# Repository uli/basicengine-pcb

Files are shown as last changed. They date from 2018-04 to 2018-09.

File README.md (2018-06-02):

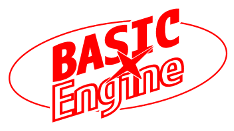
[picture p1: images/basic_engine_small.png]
BASIC Engine logo
#  BASIC Engine PCB

The BASIC Engine is a very low-cost single-board home computer with advanced 
2D color graphics and sound capabilities, roughly comparable to late-1980s
or early-1990s computers and video game consoles.  It can be built at home
without special skills or tools and using readily available components for
under 10 Euros in parts, or mass-produced for even less.

This repository contains KiCAD schematics and the PCB layout. Gerber files
for ordering PCBs can be found in the [release section](https://github.com/uli/basicengine-pcb/releases).

Software can be found in the [BASIC Engine firmware](https://github.com/uli/basicengine-firmware)
repository.

## Hardware features

- ESP12-E/F module with ESP8266 SoC and 4 MB flash memory
- VS23S010 video controller with 128k RAM and composite video output in PAL or NTSC
- 5-bit PCM sound from I2S controller
- MicroSD card slot
- PS/2 and PS/2-compatible USB keyboard interface
- PlayStation controller port
- PCF8575 I/O extender with 16 GPIO pins
- I2C and SPI busses on I/O expansion connector
- power supplied via Micro-USB socket or pin header
- RCA connectors for video and audio

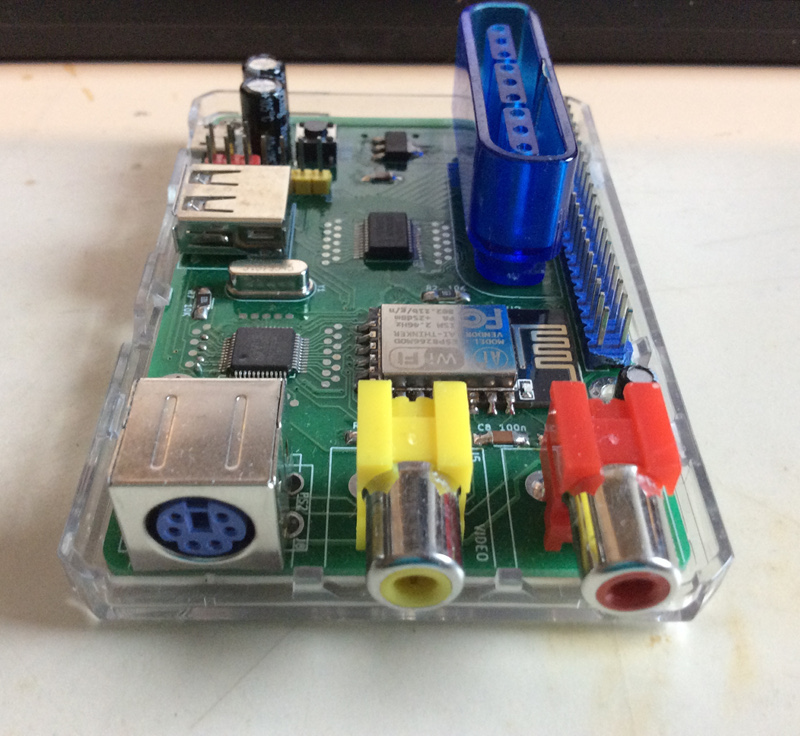
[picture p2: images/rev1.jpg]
Revision 1 board


## Components

The BASIC Engine does not use any obsolete components that may be difficult
to obtain.  Nevertheless, you will have to put in at least three orders to
get all required parts.

I would recommend to get the circuit board from JLCPCB or Smart Prototyping,
the VS23S010D-L chip from TME, and all other parts from AliExpress.  AE
usually has the lowest price, and this project is all about the cheap.

You will usually have to order more components than you actually intend to
use, because
- they are only offered in larger quantities,
- you may want to save on shipping in case you decide to build more BASIC Engines,
- you are likely to break or lose a few parts while building the device, or
- all of the above.

**Note:** Unless noted otherwise, all links lead to suppliers and components
I have bought myself in the past and that have received the "Good Enough for
BASIC Engine" seal of approval.  Nevertheless you **order at your own
risk**, and I cannot be held responsible for the quality of the services or
products provided to you.  I am not affiliated with any of the linked
suppliers.

### Required components

|Qty	|Name				|Package|Where to get it					|Links|
|---|---|---|---|-----|
|1	|Circuit Board			|	|Any board house					|[JLCPCB](https://jlcpcb.com/quote), [Smart Prototyping](https://www.smart-prototyping.com/PCB-Prototyping.html).
|1	|VS23S010D-L video controller	|	|TME (small quantities), VLSI (for large orders)	|[TME](https://www.tme.eu/en/details/vs23s010d-l/parallel-sram-memories-integ-circ/vlsi/), [VLSI](https://webstore.vlsi.fi/epages/vlsi.sf/en_GB/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)
|1	|ESP-12F or ESP-12E microcontroller module|	|AliExpress, eBay, Amazon, various smaller retailers	|AliExpress: [1](https://www.aliexpress.com/item/New-version-ESP-12E-replace-ESP-12-ESP8266-remote-serial-Port-WIFI-wireless-module/32339917567.html), [2](https://www.aliexpress.com/item/1PCS-ESP-12F-ESP-12E-upgrade-ESP8266-Remote-Serial-Port-WIFI-Wireless-Module-ESP8266-4M-Flash/32521015580.html), [3](https://www.aliexpress.com/item/1PCS-ESP-12F-ESP-12E-upgrade-ESP8266-Remote-Serial-Port-WIFI-Wireless-Module-ESP8266-4M-Flash/32521015580.html)
|8	|Resistor 10K			|1206	|Generic part						|AliExpress: [1](https://www.aliexpress.com/item/500pcs-1206-SMD-Resistor-1-10K-ohm-chip-resistor-0-25W-1-4W-103/32806664929.html), [2](https://www.aliexpress.com/item/1206-10K-ohm-5-1-4W-Resistor-3216-103-Chip-resistor-500Pcs-Lot/32601535320.html)
|1	|Resistor 1M			|1206	|Generic part						|AliExpress: [1](https://www.aliexpress.com/item/500pcs-1206-SMD-Resistor-1-1M-ohm-chip-resistor-0-25W-1-4W-106/32806720513.html)
|1	|Resistor 75 Ohms		|1206	|Generic part						|AliExpress: [1](https://www.aliexpress.com/item/100pcs-lot-1206-5-75-ohm-75R-750-1-4W-0-25W-SMD-Resistor-3-2/32681304598.html), [2 (untested supplier)](https://www.aliexpress.com/item/200pcs-lot-SMD-Chip-Resistor-1206-68R-75R-82R-91R-100R-5-Resistance-68-75-82/32830700367.html)
|2	|Resistor 1K			|1206	|Generic part						|AliExpress: [1](https://www.aliexpress.com/item/500pcs-1206-SMD-Resistor-1-1K-ohm-chip-resistor-0-25W-1-4W-102/32806736163.html)
|8	|Capacitor 100nF		|1206	|Generic part						|AliExpress: [1](https://www.aliexpress.com/item/100pcs-100NF-X7R-Error-10-50V-0-1UF-104-1206-smd-capacitor/32810080501.html), [2](https://www.aliexpress.com/item/100PCS-SMD-chip-Ceramic-capacitors-1206-104-100NF-0-1UF-1206-Y5V/1478483210.html), [3](https://www.aliexpress.com/item/100PCS-1206-104-100NF-0-1UF-1206-SMD-capacitance/32836586837.html), [4](https://www.aliexpress.com/item/Free-Shipping-100PCS-1206-104-100NF-0-1UF-1206-SMD-capacitance/1096160798.html)
|2	|Capacitor 56pF			|1206	|Generic part						|AliExpress: [1](https://www.aliexpress.com/item/100pcs-1206-smd-capacitor-25pF-27pF-30pF-33pF-36pF-39pF-47pF-51pF-56pF-68pF/32832398866.html)
|1	|Electrolytic capacitor 10uF (**Revision 1 board only!**)	|THT	|Generic part		|AliExpress: [1](https://www.aliexpress.com/item/Free-shiiping-50pcs-Aluminum-electrolytic-capacitor-10uF-50V-5-7-Electrolytic-capacitor/32326606304.html), [2](https://www.aliexpress.com/item/50-pcs-Electrolytic-Capacitors-50V-10UF-4X7MM-Aluminum-Electrolytic-Capacitor/1808204181.html)
|2	|Electrolytic Capacitor 220uF (**Revision 1 board only!**)	|THT	|Generic part		|AliExpress: [1](https://www.aliexpress.com/item/1LOT-50PCS-Aluminum-Capacitors-220uF-227-20-6-11mm-25V-220000nF-220000000pF-Diameter6mm/32707926097.html)
|1	|Capacitor 10uF (**Revision 2 board only!**)|1206	|Generic part				|AliExpress: [1](https://www.aliexpress.com/item/Free-Shopping-100PCS-smd-ceramic-capacitor-1206-3216-10uf-106-25V-10/870636274.html), [2](https://www.aliexpress.com/store/product/100PCS-LOT-10uf-Error-10-50V-106-10UF-1206-SMD-Thick-Film-Chip-Multilayer-Ceramic-Capacitor/1815642_32818359105.html)
|2	|Capacitor 22uF (**Revision 2 board only!**)|1206	|Generic part				|AliExpress: [1](https://www.aliexpress.com/item/1206-22UF-226M-Y5V-10V-SMD-Chip-Multilayer-Ceramic-Capacitor-Capacitor/32506900002.html), [2](https://www.aliexpress.com/item/100PCS-LOT-22uf-Error-10-50V-226-22UF-1206-SMD-Thick-Film-Chip-Multilayer-Ceramic-Capacitor/32818355106.html)
|2	|RCA connectors			|THT	|Generic, but often overpriced part			|AliExpress: [1 (untested supplier)](https://www.aliexpress.com/item/ROHS-high-quality-one-pin-rca-jack-connector-RCA-103P/32305697673.html); no longer available: [red](https://www.aliexpress.com/item/10-Pcs-Pcb-Mount-3-Pin-Av-Concentric-Outlet-1-Rca-Female-Socket-Board-Connector/32778665156.html), [yellow](https://www.aliexpress.com/item/20-Pcs-3P-Pcb-Mounting-Yellow-1-Rca-Female-Outlet-Jack-Audio-Video-Av-Connector/32773151735.html)
|1	|Micro-USB connector		|SMT	|Generic, but often overpriced part			|AliExpress: [1](https://www.aliexpress.com/item/10Pcs-Micro-USB-5P-5-pin-Micro-USB-Jack-5Pins-No-Curling-Micro-USB-Connector-Tail/32697562974.html), [2](https://www.aliexpress.com/item/10pcs-LOT-Micro-USB-5P-5-pin-Micro-USB-Jack-5Pins-Micro-USB-Connector-Tail-Charging/32482316889.html), [3](https://www.aliexpress.com/item/10pcs-G21-Micro-USB-5pin-DIP-Female-Connector-For-Mobile-Phone-Mini-USB-Charging-Socket-Curly/32739335401.html), [4](https://www.aliexpress.com/item/50pcs-Lot-Micro-USB-5pin-B-type-Female-Connector-For-Mobile-Phone-Micro-USB-Jack-Connector/32740232877.html)
|1	|Regulator AMS1117 3.3V		|SOT-223|Generic, sometimes overpriced part			|AliExpress: [1](https://www.aliexpress.com/item/10pcs-AMS1117-3-3-AMS1117-LM1117-1117-3-3V-1A-Voltage-Regulator/32348815272.html); eBay DE: [1](https://www.ebay.de/itm/50-Stueck-AMS1117-3-3-Niedrig-Aussetzer-Spannungsregler-3-3V-1A-SOT-223-GY-/262752156305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)
|1	|74HC04 hex inverter		|SOIC-14|Generic part						|AliExpress: [1](https://www.aliexpress.com/item/20PCS-74HC04D-SOP14-74HC04-SOP-SN74HC04DR-SMD-new-and-original-IC-free-shipping/32545540311.html), [2](https://www.aliexpress.com/item/20PCS-74HC04-SOP/32833871593.html)
|1	|Crystal 3.579545 MHz (NTSC) or 4.433619 MHz (PAL)|HC49-S	|Generic part				|AliExpress: [NTSC](https://www.aliexpress.com/item/10pcs-lot-Crystal-Oscillator-3-579545MHz-3-579545-MHz3-579545M-Hz-3-579545M-Mini-Passive-Resonator/32674141136.html), [PAL (untested supplier)](https://www.aliexpress.com/item/4-433MHZ-4-433M-HC-49S-Quartz-crystal-4-433Mhz-4-433m-DIP-Quartz-crystal-resonators/897579150.html)
|1	|PS/2 keyboard connector (female)|THT	|AliExpress, some distributors				|AliExpress: [green](https://www.aliexpress.com/item/20PCS-Lot-PS2-Green-Plug-Jack-Socket-Connector-6Pin-for-keyboard-mouse/32502046263.html), [purple](https://www.aliexpress.com/item/20PCS-Lot-PS2-Purple-Plug-Jack-Socket-Connector-6P-6Pin-for-keyboard-mouse/32503500361.html)

### Not strictly required, but strongly recommended components

|Qty	|Name				|Package|Who can supply it					|Links|
|---|---|---|---|-----|
|1	|Pin header 1x7 (programming header)|	|Generic part						|AliExpress: [1](https://www.aliexpress.com/item/1-pcs-color-2-54mm-Black-White-Red-Yellow-Blue-Green-1X40-Single-Row-Pin-Male/32776690848.html) (1x40 headers, cut them to size)
|1	|MicroSD socket			|SMT	|AliExpress, eBay					|AliExpress: [1](https://www.aliexpress.com/item/10pcs-MicroSD-Card-socket-connector-pop-up/1878206296.html), [2](https://www.aliexpress.com/item/Free-Shipping-10PCS-MicroSD-Card-socket-connector-pop-up/1688131297.html); eBay DE: [1](https://www.ebay.de/itm/10Pcs-TransFlash-SD-TF-Micro-Memory-Card-Self-eject-Socket-Adapter-Plug-NEW-/272247684402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)
|1	|Push button 6x6x4.3 mm		|THT	|Generic part						|AliExpress: [1](https://www.aliexpress.com/item/10PCS-TC-1212T-6x6x4-3-mm-Tact-Tactile-Push-Button-Momentary-SMD-PCB-Switch/32633194631.html), [2](https://www.aliexpress.com/item/20PCS-6X6X4-3-DIP-vertical-Tactile-Tact-Push-Button-Switch-Micro-Switch-Momentary-6-6-4/32628754816.html)
|1	|PCF8575TS I2C I/O extender	|SSOP-24|Generic part; AliExpress recommended for price		|AliExpress: [1](https://www.aliexpress.com/item/5PCS-PCF8575TS-SSOP24-PCF8575-SOP24/32836090166.html)
|1	|Raspberry Pi 3 case		|	|Generic part						|AliExpress: [1](https://www.aliexpress.com/item/case-H1-Black-Raspberry-PI-3-model-B-Case-Cover-Shell-Enclosure-ABS-Plastic-Box-for/32813179636.html), [2](https://www.aliexpress.com/item/box-F3-for-Raspberry-PI-3-model-B-Transparent-Green-Case-Cover-Shell-Enclosure-Box/32824924648.html), [3](https://www.aliexpress.com/item/10pcs-lot-Raspberry-Pi-3-case-Official-ABS-enclosure/32816503175.html), [4](https://www.aliexpress.com/item/New-Arrival-Raspberry-Pi-3-Model-B-Case-Black-Red-ABS-Plastic-Box-Closed-Cover-Shell/32716194619.html), [5](https://www.aliexpress.com/item/Raspberry-Pi-3-Model-B-ABS-Case-Black-White-Tranparent-ABS-Enclosure-Box-Shell-for-Raspberry/32651704900.html)

### Optional components

|Qty	|Name				|Package|Who can supply it					|Links|
|---|---|---|---|-----|
|1	|Pin header 1x3 pins (alternative power supply)|	|AliExpress recommended for price	|see "Pin header 1x7"
|1	|USB A connector (alternative keyboard connector)|THT	|Generic part				|AliExpress: [1](https://www.aliexpress.com/item/10-PCS-USB-Type-A-Female-PCB-Mount-Socket-Plug-Connector-Right-Angle-4-Pin-New/32821630374.html), [2](https://www.aliexpress.com/item/10PCS-USB-type-A-USB-mother-Curved-needle/32265708803.html)
|1	|Pin header 2x20 pins (expansion connector)|	|AliExpress recommended for price		|AliExpress: [1](https://www.aliexpress.com/item/30-pcs-set-2-54mm-Black-White-Red-Yellow-Blue-Green-2X40-Double-Row-Pin-Male/32776804458.html) (2x40 headers, cut them in half)
|1	|PlayStation controller connector (female)|	|AliExpress					|AliExpress: [1](https://www.aliexpress.com/item/10pcs-wholesale-Replacement-9-Pin-Female-Connector-Game-Controller-Socket-Slot-for-PS2-Console-for-playstation/32769355434.html), [2](https://www.aliexpress.com/item/10pcs-Replacement-9-Pin-90-degrees-Female-Connector-Game-Controller-Socket-Slot-for-PS2-Console/32818887920.html)

### Programming tools

Used to flash the firmware into the microcontroller module. You only need one set of these.

|Qty	|Name				|Package|Who can supply it				|Links|
|---|---|---|---|-----|
|1	|USB-to-serial converter	|	|AliExpress, eBay				|AliExpress: [1](https://www.aliexpress.com/item/1pcs-FT232RL-FTDI-USB-3-3V-5-5V-to-TTL-Serial-Adapter-Module-forArduino-Mini-Port/32650148276.html), [2](https://www.aliexpress.com/item/CP2102-USB-2-0-to-TTL-UART-Module-6Pin-Serial-Converter-STC-Replace-FT232-Module/32279672853.html)
|7	|Dupont wires female/female (for wiring the converter to the programming header)|	|AliExpress, eBay	|AliExpress: [1 (untested supplier)](https://www.aliexpress.com/item/40pcs-dupont-cable-jumper-wire-dupont-line-female-to-female-dupont-line-20cm-1P-40P-free/32848338475.html), [2 (untested supplier)](https://www.aliexpress.com/item/40pcs-dupont-cable-jumper-wire-dupont-line-female-to-female-dupont-line-20cm-1P-1P-for/32586620163.html)

## Ordering the PCB

If you have never had a custom circuit board made, you may find the
multitude of options you are presented with on the board house's ordering
page confusing.  The good news is that you do not have to worry about most
of them, because they have been set to reasonable defaults already.  If you
order with JLCPCB or Smart Prototyping using the links above, all you have
to do is upload the ZIP file containing the Gerber files that you can find
in the [release section](https://github.com/uli/basicengine-pcb/releases)
and specify the dimensions of the board (85x56 mm).  All other options can
be left as is.

(Just to be on safe side: At the time of writing these options were: 2
layers, 1.6 mm thickness, HASL with lead, 1oz copper weight, material FR4.)

## Assembling the BASIC Engine

Even though it uses some small-pitch components, the BASIC Engine has been
designed to be easy to assemble.

Click on the thumbnail below to watch a one-hour silent video showing how to
build it using a soldering iron, a heat gun, tweezers,
solder wire and side cutters, without fancy tools, mad soldering skills and
with only a minimal amount of patience:

Assembling the BASIC Engine (http://www.youtube.com/watch?v=DTTEZJDEUIA "BASIC Engine Soldering")

## PCB Errata

Revision 2 of the PCB contains one error:

- R6 value is given as "22R", should be "75R".

Revision 1 of the PCB contains two errors:

- R6 value is given as "22R", should be "75R".
- C3 and C4 values are given as "10p", should be "56p".

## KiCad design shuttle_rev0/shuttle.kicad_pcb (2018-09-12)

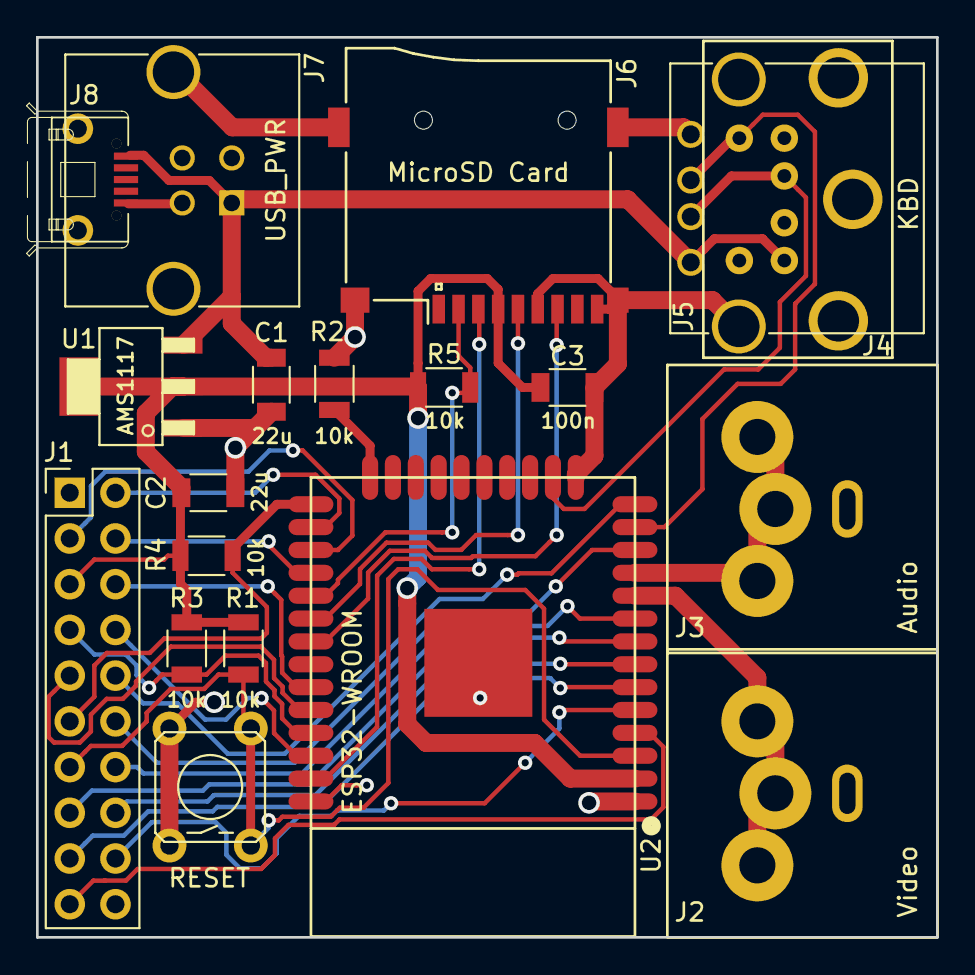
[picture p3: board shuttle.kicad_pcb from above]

Board: 2 copper layers, 50.0 x 50.0 mm, 19 parts (0 on the bottom side), 29 nets.

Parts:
C1, C2: 22u; C_1206
C3: 100n; C_1206
J1: EXP; Pin_Header_Straight_2x10_Pitch2.54mm
J2: Video; rca_uni
J3: Audio; rca_uni
J4: PS2_KBD; MINI-DIN-6-FULL-SHIELD
J5: KBD; USB_A
J6: MicroSD Card; Conn_uSDcard
J7: USB_PWR; USB_B_MUSB_Straight
J8: USB_PWR_U; AB2_USB_MICRO_SMD
R1, R2, R3, R4, R5: 10k; R_1206
SW1: RESET; AB2_PB_MOM_6MM_PTH_BLK
U1: AMS1117; AB2_SOT223
U2: ESP32-WROOM

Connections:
+5V: C1.1, J4.4, J5.1, J7.1, J8.1, U1.3
/3V3: C2.1, C3.1, J1.5, J6.4, R1.2, R3.1, R4.1, R5.1, U1.2, U2.2
/AUDIO: J3.1, U2.11
/DBG_DTR: J1.11, R4.2, U2.25
/DBG_RX: J1.9, U2.34
/DBG_TX: J1.7, R3.2, U2.35
/EN: J1.13, R1.1, SW1.2, U2.3
/GPIO2: R2.1, U2.24
/GPIO4: J1.2, U2.26
/GPIO12: J1.10, U2.14
/GPIO16: J1.3, U2.27
/GPIO17: J1.4, U2.28
/GPIO21: J1.6, U2.33
/GPIO22: J1.8, U2.36
/GPIO27: J1.12, U2.12
/GPIO32: J1.15, U2.8
/GPIO33: J1.14, U2.9
/GPIO34: J1.17, U2.6
/GPIO35: J1.16, U2.7
/MISO: J6.7, U2.31
/MOSI: J6.3, U2.37
/PS2CLK: J4.5, J5.3, U2.13
/PS2DAT: J4.1, J5.2, U2.16
/SCLK: J6.5, U2.30
/SDCS: J6.2, R5.2, U2.29
/SENSOR_VN: J1.18, U2.5
/SENSOR_VP: J1.19, U2.4
/VIDEO: J2.1, U2.10
GND: C1.2, C2.2, C3.2, J1.1, J1.20, J2.2, J3.2, J4.3, J5.4, J5.5, J6.6, J6.9, J7.4, J7.5, J8.5, R2.2, SW1.1, U1.1, U2.1, U2.15, U2.38, U2.39

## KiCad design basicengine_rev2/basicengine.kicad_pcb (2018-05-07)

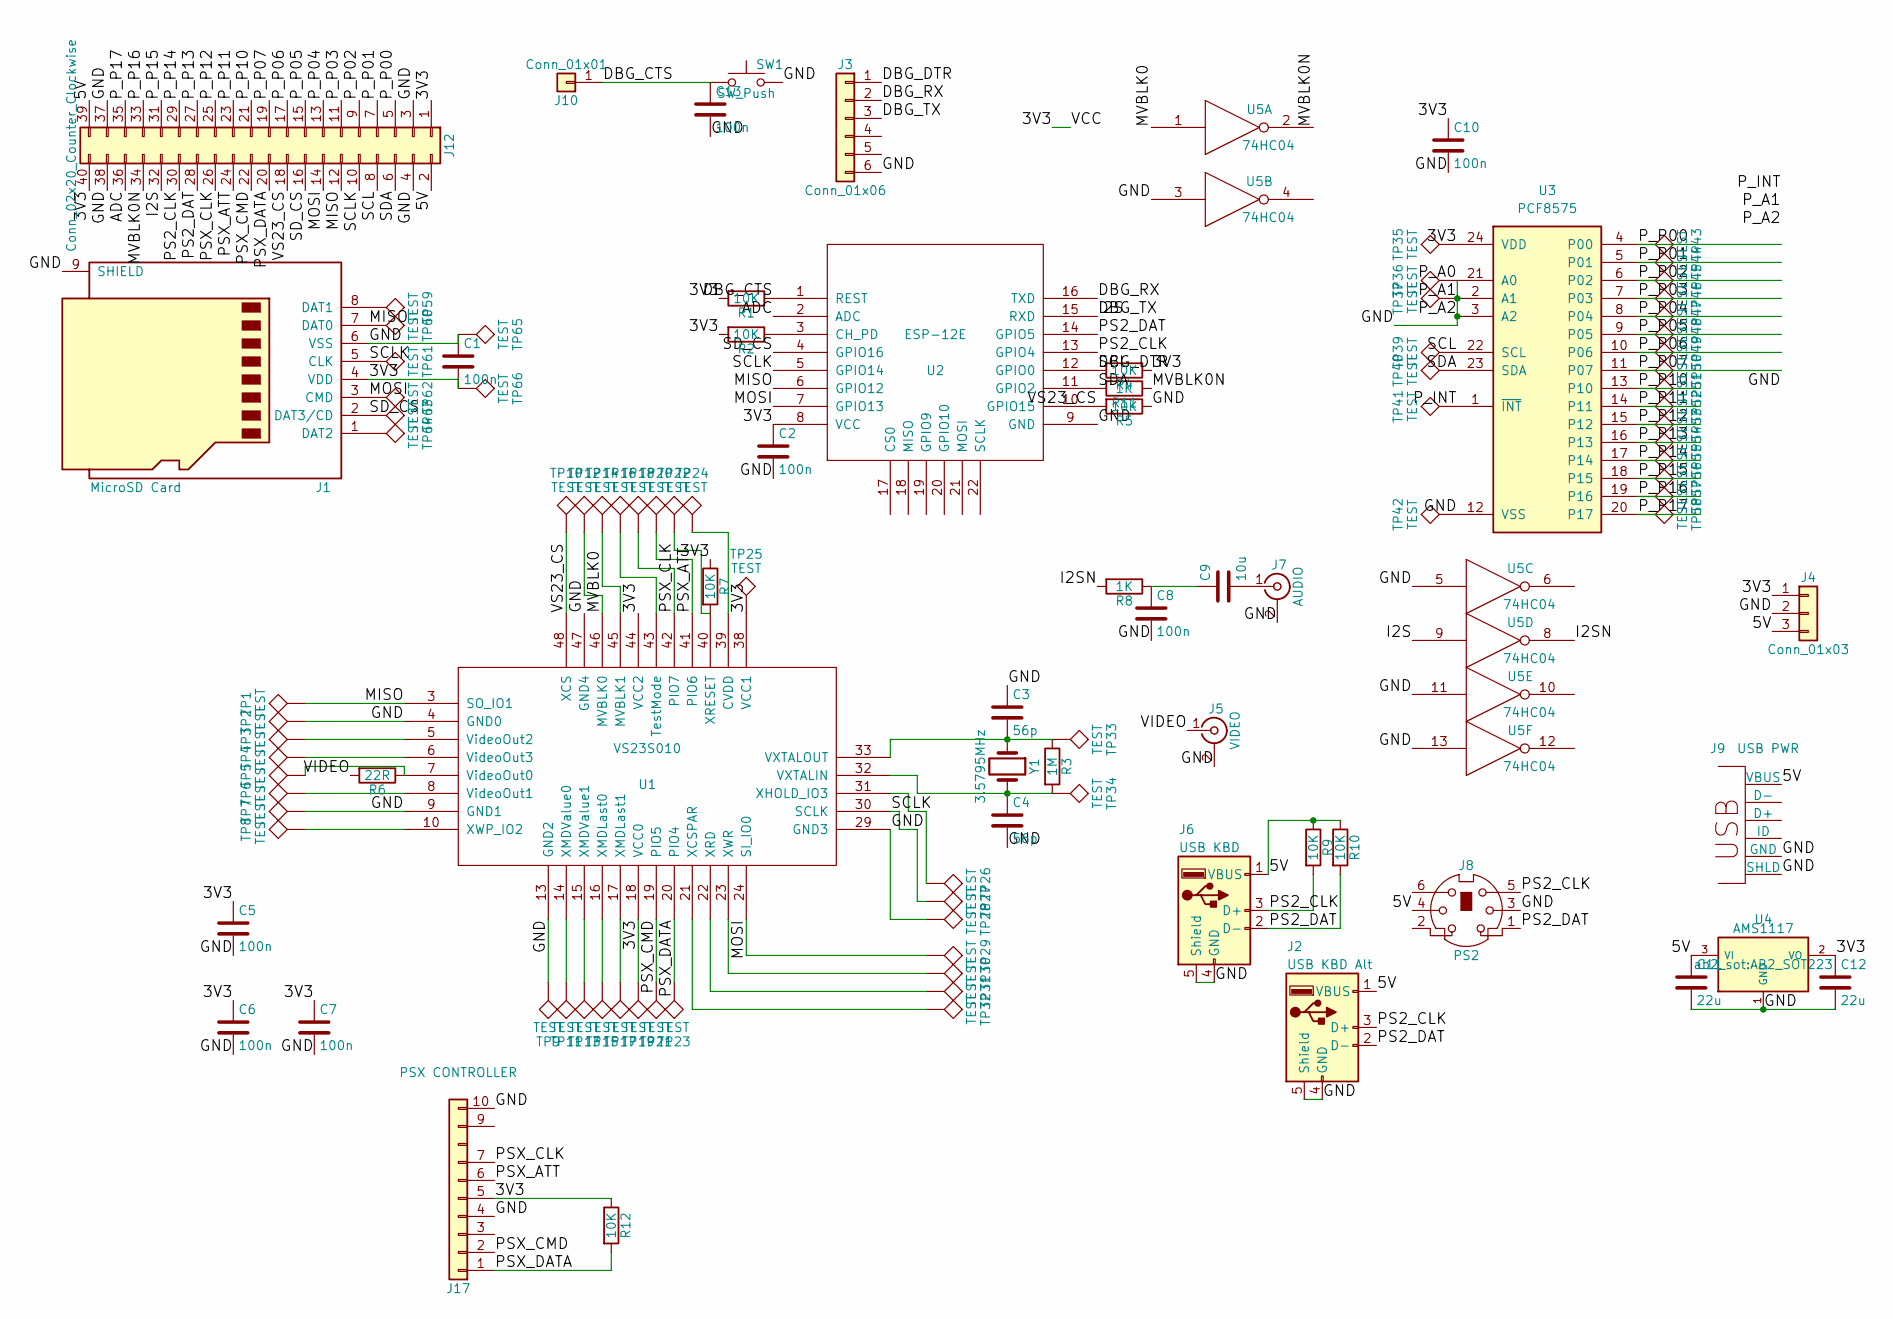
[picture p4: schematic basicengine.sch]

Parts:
C1, C2, C5, C6, C7, C8, C10, C13: 100n; C_1206_HandSoldering
C3, C4: 56p; C_1206_HandSoldering
C9: 10u; C_1206_HandSoldering
C11, C12: 22u; C_1206_HandSoldering
J1: MicroSD Card; Conn_uSDcard
J2: USB KBD Alt; USB_A
J3: Conn_01x06; Pin_Header_Straight_1x06
J4: Conn_01x03; Pin_Header_Straight_1x03
J5: VIDEO; rca
J6: USB KBD; USB_A
J7: AUDIO; rca
J8: PS2; MINI-DIN-6-FULL-SHIELD
J9: USB PWR; AB2_USB_MICRO_SMD
J10: Conn_01x01; Pin_Header_Straight_1x01
J12: Conn_02x20_Counter_Clockwise; Pin_Header_Straight_2x20
J17: PSX CONTROLLER; psx-con-female
R1, R2, R4, R5, R7, R9, R10, R12: 10K; R_1206_HandSoldering
R3: 1M; R_1206_HandSoldering
R6: 22R; R_1206_HandSoldering
R8, R11: 1K; R_1206_HandSoldering
SW1: SW_Push; AB2_PB_MOM_6MM_PTH_BLK
TP1, TP2, TP3, TP4, TP5, TP6, TP7, TP8, TP9, TP10, TP11, TP12, TP13, TP14, TP15, TP16, TP17, TP18, TP19, TP20, TP21, TP22, TP23, TP24, TP25, TP26, TP27, TP28, TP29, TP30, TP31, TP32, TP33, TP34, TP35, TP36, TP37, TP39, TP40, TP41, TP42, TP43, TP44, TP45, TP46, TP47, TP48, TP49, TP50, TP51, TP52, TP53, TP54, TP55, TP56, TP57, TP58, TP59, TP60, TP61, TP62, TP63, TP64, TP65, TP66: TEST; Measurement_Point_Round-SMD-Pad_Small
U1: VS23S010; LQFP-48_7x7mm_Pitch0.5mm
U2: ESP-12E; ESP-12E_SMD
U3: PCF8575; SSOP-24_5.3x8.2mm_Pitch0.65mm; MPN PCF8575TS/1,112
U4: AMS1117; AB2_SOT223
U5: 74HC04; SOIC-14_3.9x8.7mm_Pitch1.27mm
Y1: 3.5795MHz; Crystal_HC49-U_Vertical

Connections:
/5V: C11.1, J2.1 (VBUS), J4.3, J6.1 (VBUS), J8.4, J9.1 (VBUS), J12.2, J12.39, R9.1, R10.1, U4.3 (VI)
/ADC: J12.36, U2.2 (ADC)
/DBG_CTS: C13.1, J10.1, R1.1, SW1.1, U2.1 (REST)
/DBG_DTR: J3.1, J12.8, R4.2, TP39.1, U2.12 (GPIO0), U3.22 (SCL)
/DBG_RX: J3.2, U2.16 (TXD)
/DBG_TX: J3.3, J12.32, U2.15 (RXD), U5.9
/I2SN: R8.2, U5.8
/MISO: J1.7 (DAT0), J12.12, TP1.1, TP60.1, U1.3 (SO_IO1), U2.6 (GPIO12)
/MOSI: J1.3 (CMD), J12.14, TP29.1, TP62.1, U1.24 (SI_IO0), U2.7 (GPIO13)
/MVBLK0: TP12.1, U1.46 (MVBLK0), U5.1
/MVBLK0N: J12.34, R11.1, U5.2
/PS2_CLK: J2.3 (D+), J6.3 (D+), J8.5, J12.30, R9.2, U2.13 (GPIO4)
/PS2_DAT: J2.2 (D-), J6.2 (D-), J8.1, J12.28, R10.2, U2.14 (GPIO5)
/PSX_ATT: J12.24, J17.6, TP20.1, U1.41 (PIO6)
/PSX_CLK: J12.26, J17.7, TP18.1, U1.42 (PIO7)
/PSX_CMD: J12.22, J17.2, TP21.1, U1.19 (PIO5)
/PSX_DATA: J12.20, J17.1, R12.2, TP23.1, U1.20 (PIO4)
/P_INT: TP41.1, U3.1 (~INT)
/P_P00: J12.5, TP43.1, U3.4 (P00)
/P_P01: J12.7, TP44.1, U3.5 (P01)
/P_P02: J12.9, TP45.1, U3.6 (P02)
/P_P03: J12.11, TP46.1, U3.7 (P03)
/P_P04: J12.13, TP47.1, U3.8 (P04)
/P_P05: J12.15, TP48.1, U3.9 (P05)
/P_P06: J12.17, TP49.1, U3.10 (P06)
/P_P07: J12.19, TP50.1, U3.11 (P07)
/P_P10: J12.21, TP51.1, U3.13 (P10)
/P_P11: J12.23, TP52.1, U3.14 (P11)
/P_P12: J12.25, TP53.1, U3.15 (P12)
/P_P13: J12.27, TP54.1, U3.16 (P13)
/P_P14: J12.29, TP55.1, U3.17 (P14)
/P_P15: J12.31, TP56.1, U3.18 (P15)
/P_P16: J12.33, TP57.1, U3.19 (P16)
/P_P17: J12.35, TP58.1, U3.20 (P17)
/SCLK: J1.5 (CLK), J12.10, TP27.1, TP61.1, U1.30 (SCLK), U2.5 (GPIO14)
/SDA: J12.6, R11.2, TP40.1, U2.11 (GPIO2), U3.23 (SDA)
/SD_CS: J1.2 (DAT3/CD), J12.16, TP63.1, U2.4 (GPIO16)
/VIDEO: J5.1 (In), R6.2
/VS23_CS: J12.18, R5.2, TP10.1, U1.48 (XCS), U2.10 (GPIO15)
GND: C1.1, C2.2, C3.1, C4.2, C5.2, C6.2, C7.2, C8.2, C10.2, C11.2, C12.2, C13.2, J1.6 (VSS), J1.9 (SHIELD), J2.4 (GND), J2.5 (Shield), J3.6, J4.2, J5.2 (Ext), J6.4 (GND), J6.5 (Shield), J7.2 (Ext), J8.3, J9.5 (GND), J9.SH (SHLD), J12.3, J12.4, J12.37, J12.38, J17.4, J17.10, R5.1, SW1.2, TP2.1, TP7.1, TP9.1, TP28.1, TP36.1, TP37.1, TP42.1, TP65.1, U1.4 (GND0), U1.9 (GND1), U1.13 (GND2), U1.29 (GND3), U1.47 (GND4), U2.9 (GND), U3.2 (A1), U3.3 (A2), U3.12 (VSS), U3.21 (A0), U4.1 (GND), U5.3, U5.5, U5.7 (GND), U5.11, U5.13
unnamed: C3.2, R3.1, TP33.1, U1.33 (VXTALOUT), Y1.1
unnamed: C4.1, R3.2, TP34.1, U1.32 (VXTALIN), Y1.2
unnamed: C8.1, C9.1, R8.1
unnamed: C9.2, J7.1 (In)
unnamed: J1.1 (DAT2), TP64.1
unnamed: J1.8 (DAT1), TP59.1
unnamed: R2.1, U2.3 (CH_PD)
unnamed: R6.1, TP5.1, U1.7 (VideoOut0)
unnamed: R7.2, TP22.1, U1.40 (XRESET)
unnamed: TP3.1, U1.5 (VideoOut2)
unnamed: TP4.1, U1.6 (VideoOut3)
unnamed: TP6.1, U1.8 (VideoOut1)
unnamed: TP8.1, U1.10 (XWP_IO2)
unnamed: TP11.1, U1.14 (XMDValue0)
unnamed: TP13.1, U1.15 (XMDValue1)
unnamed: TP14.1, U1.45 (MVBLK1)
unnamed: TP15.1, U1.16 (XMDLast0)
unnamed: TP16.1, U1.43 (TestMode)
unnamed: TP17.1, U1.17 (XMDLast1)
unnamed: TP24.1, U1.39 (CVDD)
unnamed: TP26.1, U1.31 (XHOLD_IO3)
unnamed: TP30.1, U1.23 (XWR)
unnamed: TP31.1, U1.22 (XRD)
unnamed: TP32.1, U1.21 (XCSPAR)
VCC: C1.2, C2.1, C5.1, C6.1, C7.1, C10.1, C12.1, J1.4 (VDD), J4.1, J12.1, J12.40, J17.5, R1.2, R2.2, R4.1, R7.1, R12.1, TP19.1, TP25.1, TP35.1, TP66.1, U1.18 (VCC0), U1.38 (VCC1), U1.44 (VCC2), U2.8 (VCC), U3.24 (VDD), U4.2 (VO), U5.14 (VCC)

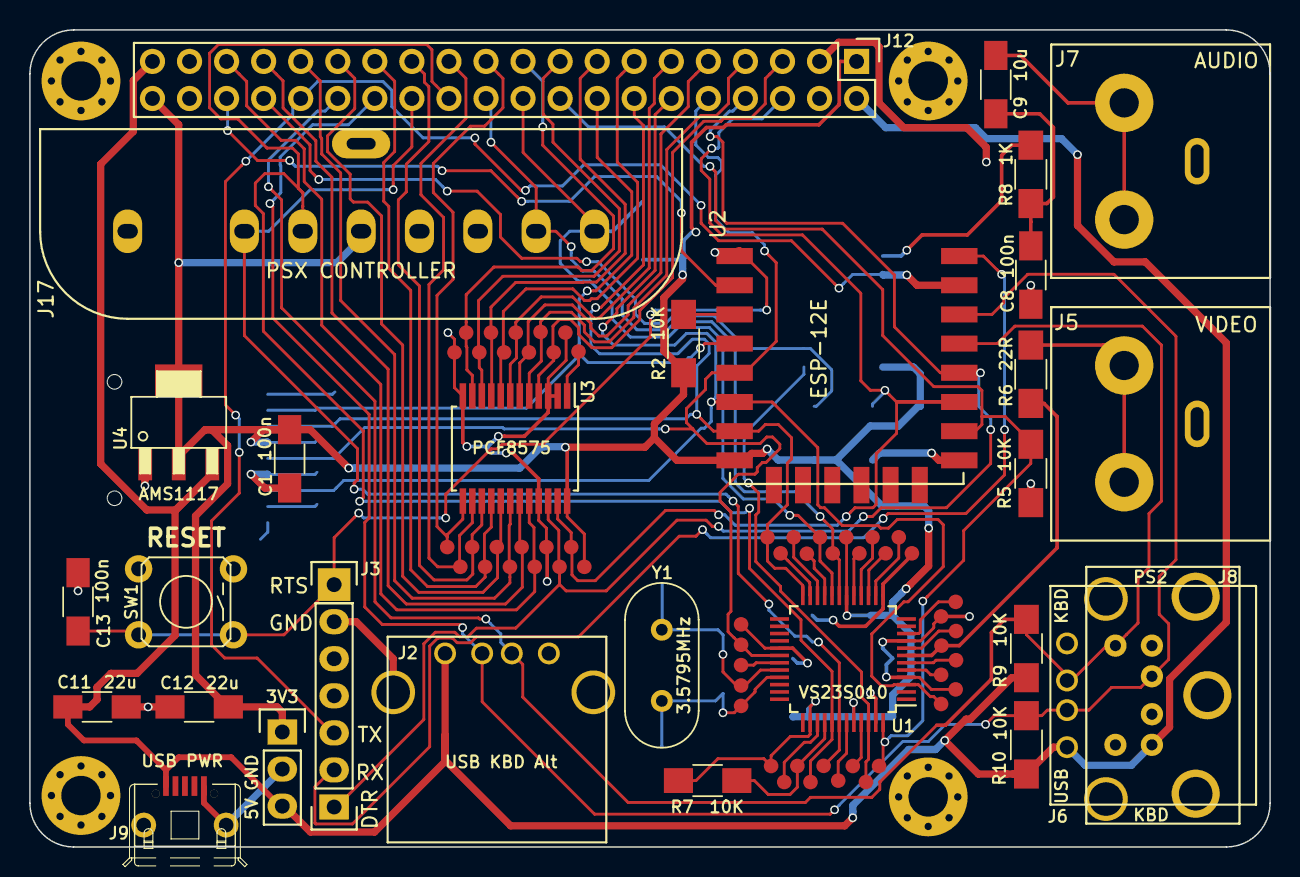
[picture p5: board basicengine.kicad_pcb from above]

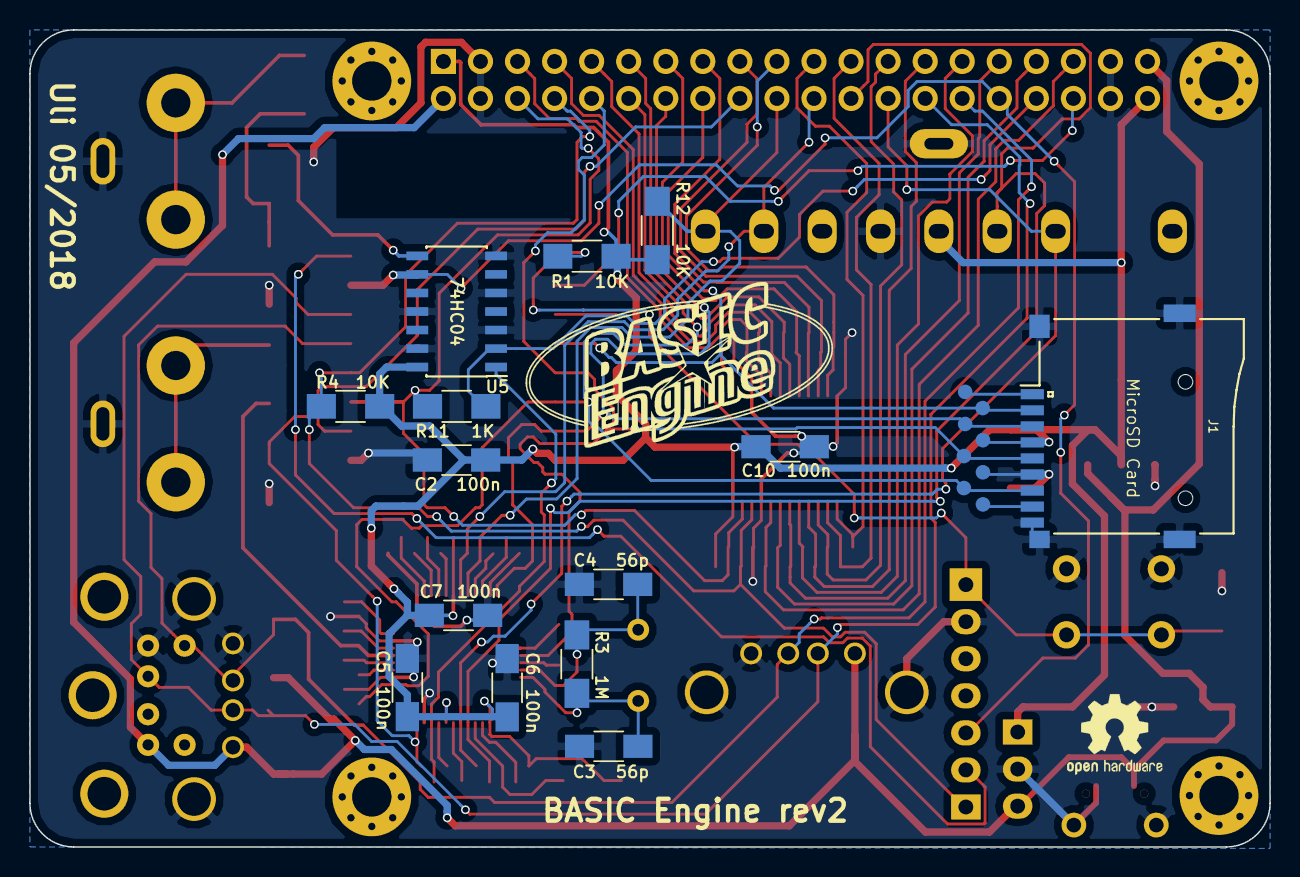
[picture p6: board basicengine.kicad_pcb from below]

Board: 2 copper layers, 85.0 x 56.0 mm, 109 parts (22 on the bottom side), 65 nets.

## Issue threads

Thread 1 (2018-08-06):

USB controller support?

darkhog, 2018-08-06:
I think it'd be good if the PSX port would be replaced with a standard USB port or few. Not only USB is much more common than PSX and therefore the part would be cheaper, but also it's easy to find a cheap, DirectInput-based USB controllers for around $5. I know it's a big change and would require rewriting parts of the firmware as well, but in the coming years, original Playstation controllers will be harder and harder to come by, while there will be always some cheap USB dualshock clone in a store near you.

uli, 2018-08-08:
It would obviously be a good thing to have that, but there are numerous issues with it. The software side is actually not so much of a problem; I have working HID driver code for the CH376 USB host controller. The real problems are on the hardware side. Let's review some potential approaches:

1. Adding USB to the current design

The current BE design does not leave any resources that would allow hooking up a USB host controller. The CH376 that I have used in the predecessor to this project can be connected via UART or SPI. (Also via Motorola or Intel-style parallel memory bus, but let's not go there...)

We do not have any UARTs available, and we do not even have a free GPIO to use as a slave select. Using the I/O extender for the SS is not likely to perform well enough; IIRC, the CH376's SPI interface requires all commands to be delimited by a rising edge on the SS, so that pin would have to be toggled a lot, which is probably prohibitively slow via the I2C extender.

So even when considering it an external peripheral (and thus disregarding the cost), it would probably not work well enough.

2. New design using an MCU with built-in USB host controller

The ESP32, a natural upgrade path from the ESP8266,  does not feature any USB support. There is a number of MCUs featuring USB OTG or host support. The catch is that there aren't many, they are really expensive (the STM32F411RET6 typically has a street price around 4 Euros) and at the same time often underpowered in terms of RAM, not to mention the lack of wireless capabilities. I don't know for sure why they are so expensive, or why the ESP32 does not have USB support, but I suspect both have something to do with patent licenses...

3. New design using an external USB host controller

On a platform not as hardware resource-constrained, incorporating a USB host controller such as the CH376 would be technically viable. While it would increase the complexity of the system, the whole USB subsystem can be declared optional, basically limiting the impact to having some extra pads on the PCB. That would also mean that the cost (ca. 0.76 Euros for the chip, plus 12 MHz crystal and some passives) would not have to be borne by those not in need of this feature.

In summary, I think this is something to be considered for a next-generation design.

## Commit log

2018-04-28 import revision 1
    [basicengine.kicad_pcb, basicengine.sch]
2018-04-30 README.md: add component, assembly information, logo
2018-05-07 sch: replace THT electrolytics with ceramic SMT caps
    Reduces regulator in/out capacitors from 220u to 22u; tested by writing
    data from network to SD card, seems to be stable.
    [basicengine.sch]
2018-05-07 sch: change VS23S010 oscillator caps from 10p to 56p
    Yields more accurate color burst frequency, fixes B/W display on Sony
    KX-14CP1.
    [basicengine.sch]
2018-05-07 pcb: add OSHW logo
    [basicengine.kicad_pcb]
2018-05-07 pcb: follow sch oscillator capacitor change from 10p to 56p
    [basicengine.kicad_pcb]
2018-05-07 pcb: revision 2
    - follow sch in replacing electrolytics with ceramic SMT caps
    - move J6 (primary USB KBD connector) left to reduce the proximity of
    its pads to the shielding of J8 (PS/2 connector)
    - move R9, R10 left to make space for J6
    - move BASIC Engine logo down a bit
    - update date and revision silkscreen
    [basicengine.kicad_pcb]
2018-09-12 move BASIC Engine rev2 design to directory basicengine_rev2
    [basicengine.kicad_pcb, basicengine.sch]
2018-09-12 add BASIC Engine Shuttle rev0 design
    [shuttle.kicad_pcb, shuttle.sch]
